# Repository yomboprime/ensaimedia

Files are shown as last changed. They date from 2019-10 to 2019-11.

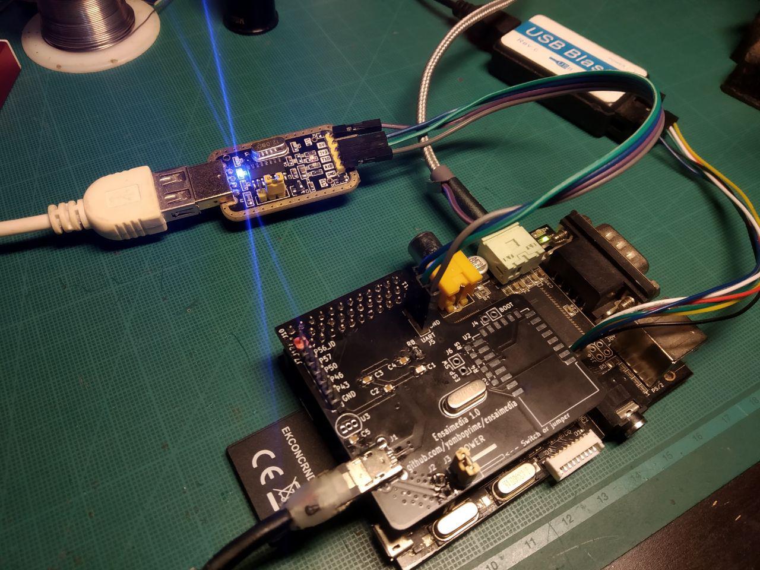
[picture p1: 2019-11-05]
screenshots/foto3.jpeg

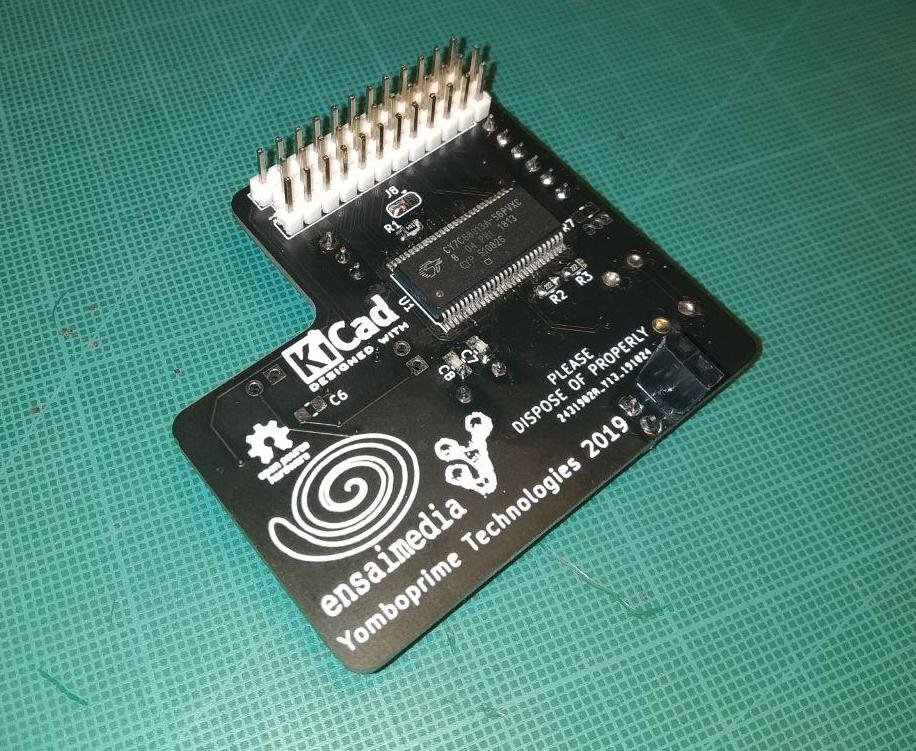
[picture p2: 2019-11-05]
screenshots/foto2.jpeg

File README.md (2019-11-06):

# Ensaimedia

Ensaimedia permite ver la salida de vídeo de un ZX-Uno o otra FPGA en un ordenador con USB host. Adicionalmente permite redireccionar el teclado, ratón y gamepads del host al ZX-Uno vía puerto serie. La salida de sonido del ZX-Uno también es capturada por el host si dispone de entrada de MIC o de línea de audio. La visualización se realiza desde el navegador web, ya sea en el host, o en otro dispositivo remoto. Por último, permite capturar vídeo y audio a disco.

El desarrollo de este addon ha sido posible gracias a la información y software de Wolfgang Wieser sobre el chip Cypress FX2 [en este sitio web.](https://www.triplespark.net/elec/periph/USB-FX2)

# Índice

En este README:
- [Guía de usuario](https://github.com/yomboprime/ensaimedia#guia-de-usuario-de-ensaimedia)
- [Documentación del protocolo](https://github.com/yomboprime/ensaimedia#documentaci%C3%B3n-ensaimedia)

En este repositorio:
- [Binarios de los cores](https://github.com/yomboprime/ensaimedia/tree/master/cores/)
- [Esquemático y PCB (en formato Kicad)](https://github.com/yomboprime/ensaimedia/tree/master/ensaimediaBoard)
- [Esquemático en formato PDF](https://github.com/yomboprime/ensaimedia/tree/master/ensaimediaBoard/ensaimedia.pdf)
- [Código del servidor](https://github.com/yomboprime/ensaimedia/blob/master/server.js)
- [Código del cliente](https://github.com/yomboprime/ensaimedia/blob/master/client/src/client.js)

# Guia de usuario de Ensaimedia

## Requisitos en el ZX-Uno

Necesitas el addon de Ensaimedia para tu FPGA, así como instalar el core de Ensaimedia de tu máquina retro.

Actualmente sólo está disponible el core oficial de ZX-Uno para ZX Spectrum.

## Requisitos del software Ensaimedia del host:

El host debe ser un sistema Unix, debido a que se usa el programa [fx2pipe](https://www.triplespark.net/elec/periph/USB-FX2/software/fx2pipe.html) para la entrada de vídeo por USB. El cliente (o clientes) puede ser cualquier sistema con un navegador web moderno.

- Ejecuta lo siguiente para instalar los requisitos previos:

`sudo apt install git npm libusb-dev build-essential`

- Pon a tu usuario en el grupo dialout para poder acceder al puerto serie:

`sudo adduser <nombre_de_usuario> dialout`

(Necesitas salir de la sesión o reiniciar para aplicar la adición al grupo, pero puedes reiniciar al terminar la instalación)

## Instalación del software Ensaimedia

Ve al directorio que se desea contenga el directorio de Ensaimedia.

Ejecuta:

```
git clone https://github.com/yomboprime/ensaimedia.git
cd ensaimedia
npm install
```

Adicionalmente hay que instalar unas reglas UDEV. Para ello ejecuta lo siguiente desde el directorio de Ensaimedia:

`sudo cp ./udevrules/z70_usbfx2.rules /etc/udev/rules.d`

Despues reinicia.

## Configuración del software

Edita el fichero `EnsaimediaConfig.json` que está en la raíz de la aplicación:

Como mínimo querrás cambiar el puerto TCP en el que sirve Ensaimedia (opción `listenPort`)

La ruta del fichero del puerto serie se cambia en la opción `serialPortFilePath`.

Si vas a usar audio necesitas primero identificar el dispositivo de audio de tu tarjeta de sonido. Para ello ejecuta:

`arecord -L`

Y verás una lista de dispositivos de entrada de audio. Tendrás que ir probando hasta dar con el mejor; algunos pueden funcionar peor o tener lag.

Copia la primera línea de uno de ellos y pégala (entre comillas) en la opción "audioDevice" en el fichero de configuración.

Para las opciones de guardado a disco mira la sección "Captura a disco" de esta documentación.

## Ejecución de Ensaimedia

Para utilizar Ensaimedia sigue estos pasos:

- Enciende el host.
- Conecta la FPGA al host (ver sección correspondiente más abajo)
- Activa en la FPGA el core deseado de Ensaimedia
- Ejecuta el software de Ensaimedia en el host.

Para ejecutar Ensaimedia sirve una cualquiera de estas tres variantes (en el directorio de Ensaimedia):

- `./Ensaimedia.sh`
- `node server.js`
- `npm start`

Para terminar el programa en cualquier momento, pulsa Ctrl-c en la consola donde lo has abierto.

Al ejecutar verás algunos mensajes indicando los recursos que está abriendo el programa. Si todo va bien, al cabo de un segundo verás el mensaje "New graphic mode: XXXxYYY", que indica que se ha activado el vídeo con esa resolución.

Ahora abre desde un navegador la url: `http://<IP del host>:<puerto TCP configurado>/main.html`

Por ejemplo, si estás abriendo el navegador desde el propio host y el puerto que editaste en `EnsaimediaConfig.json` fue el 12345, abre la url:

`http://127.0.0.1:12345/main.html`

Al abrir la URL ya deberá verse la pantalla de vídeo de la retromáquina.

## Uso de Ensaimedia

El teclado, ratón y dos gamepads funcionan de forma transparente.

Para activar el sonido debes ir al menú, arriba a la derecha (las páginas HTML no permiten reproducción de sonido sin intervención del usuario)

En el menú verás algunas opciones visuales:

- `Pixelated screen`: Hace que los píxels se vean nítidos en vez de interpolados. Nota: De momento no funciona en Firefox.
- `Interlazed`: Mezcla dos fotogramas consecutivos para ver correctamente demos con entrelazado.
- `Resolution is múltiple`: Hace que la resolución de salida sea múltiplo de la nativa de la máquina. Si está desactivada entonces la pantalla se ajusta mejor al espacio disponible pero puede haber píxeles irregulares.
- `Show info on screen`: Muestra en la esquina superior izquierda información de frames por segundo, clientes conectados y audio.
- `Toggle full screen`: Cambia entre modo pantalla completa y ventana.
- `Audio enabled`: Habilita el sonido.
- `Input options`: Aqui puedes activar o desactivar el envío de eventos de teclado, ratón y gamepads.
- `Open/close Controls`: Minimiza o expande el menú.

## Captura a disco

Para activar la captura a disco, establece a `true` los valores `saveVideoToDiskEnabled` y/o `saveAudioToDiskEnabled` en el fichero de configuración `EnsaimediaConfig.json`.

La captura se realiza en el host, los clientes del navegador no pueden afectar a esta.

La captura comenzará tan pronto como haya señal de vídeo, y la sesión se guardará en una carpeta nueva bajo `Ensaimedia/savedSessions/` (con nombre dependiente de la fecha y hora) como dos ficheros: `video.bin` con el vídeo en raw, y `audio.wav` con el audio. Estos ficheros continuarán creciendo mientras esté funcionando el programa, a un ritmo aproximado de 500 MB por minuto (para el core de ZX Spectrum con vídeo y audio).

Tras finalizar la sesión de Ensaimedia hay que postprocesar los datos raw para generar un vídeo comprimido webm "píxel perfect" que se pueda reproducir. Este proceso puede tardar 10 veces lo que dura el vídeo. Para ello:

- Abre un terminal de consola en la carpeta de Ensaimedia
- Ejecuta la orden `node convertCapture.js <carpeta> ni FPS`, donde:
	- `<carpeta>` es el nombre de la subcarpeta bajo `savedSessions`, sin barras.
	- `ni` Significa "not interlazed". Pon `i` en su lugar si quieres que se mezclen fotogramas dos a dos para desentrelazar el vídeo (el vídeo de salida tendrá la mitad de FPS)
	- FPS son los FPS originales del vídeo, 50 para el core de  ZX Spectrum. Puede contener decimales. El valor es independiente de si seleccionas entrelazado o no.

Este proceso convierte el vídeo raw a imágenes `.png` que ocupan otro tanto, y después llama al programa `ffmpeg` para crear el vídeo webm. En todo momento se muestra el estado de la conversión.

Al terminar se habrá creado el fichero `video.webm` en la subcarpeta de la sesión. Puedes entonces borrar el resto de ficheros. Puedes volver a crear el vídeo en cualquier momento si los ficheros `video.bin` y `audio.wav` están presentes (el fichero de audio es opcional)

## Conexión del ZX-Uno al host

Hay tres conexiones por cable entre el host y la FPGA: Un cable microUSB para el vídeo, un puerto serie para periféricos y RTC, y el cable de audio analógico.

Muy importante (Sólo para ZX-Uno): No conectes el microUSB de alimentación normal del ZX-Uno mientras usas el addon de Ensaimedia. Tanto el ZX-Uno como el addon son alimentados por el cable microUSB de éste último.

### Cable MicroUSB

Este cable conecta el host a la FPGA mediante un cable microUSB con líneas de datos (hay cables que sólo sirven para cargar y no tienen los cables que transportan los datos, sólo los de alimentación)

Este cable alimenta al ZX-Uno y al addon.

Es importante que el puerto del host sea USB 2.0 o superior. No sirve USB 1.0 ó 1.1.

### Cable puerto serie

Si el host tiene puerto serie de 3.3V accesible, puedes conectarlo directamente con tres cables Dupont (los comunes de 2.54 mm de separación). Si no, necesitarás un dongle USB Serial **que tenga jumper para configurarse a 3.3V (5V no vale)** y ocupar un puerto USB más.

La conexión de los tres cables Dupont en cualquier caso es la siguiente (verás el conector en el addon indicado como "serial" y los pines "RX", "TX" y "GND":

```
RX de la FPGA <--- TX del dongle
TX de la FPGA ---> RX del dongle
GND de la FPGA --- GND del dongle
```

### Cable de audio

Es un simple cable de audio estéreo minijack macho-macho. Se conecta desde la salida de sonido de la FPGA a la entrada de mic o de línea en el host.

Puede que necesites usar alsamixer para ajustar el volumen de la entrada.

## Problemas conocidos

En el propio host y en red local (LAN) el sonido funciona bien. Sin embargo, debido a que se usa WebRTC, para usar el sonido en Ensaimedia desde dispositivos que no tienen una IP pública (o si el host no tiene IP pública) habría que usar un "TURN server". No se ha implementado aún esta posibilidad, al no existir servidores TURN de acceso público.

-------------------------------------

# Documentación Ensaimedia

Ensaimedia consiste en una interfaz de comunicación entre un ZX-Uno (o otra FPGA) y un host USB mediante USB 2.0, para transmisión de vídeo al host, además de una interfaz serie (UART) para transmitir información de periféricos desde el host al ZX-Uno. Adicionalmente el software del host permite entrada y salida de audio analógico, conectando LINE y EAR del ZX-Uno a MIC y LINE del host.

Esto permite:

- Usar la salida HDMI del host (o cualquier salida futura) como nativa del core de ZX-Uno.
- Usar periféricos USB en el host como entrada en el ZX-Uno: Teclado, ratón y gamepads.
- Virtualizar completamente el ZX-Uno y hacerlo disponible a clientes web, cada uno con sus periféricos y recepción de vídeo y audio.
- Capturar a disco la sesión de vídeo y audio.

Las salidas de vídeo nativas así como los periféricos nativos del ZX-Uno se pueden usar a la vez que Ensaimedia, o bien se pueden dejar desconectados.

# Interfaz física de Ensaimedia

## Interfaz de vídeo

La interfaz de vídeo en Ensaimedia 1.0 consiste en un bus síncrono en el que el ZX-Uno es el master, y un chip Cypress CY7C68013A-56PVXC (FX2LP) lee ese bus y envía los datos por USB 2.0.

El bus es de 16 bits de ancho. El máximo ancho de banda teórico del bus es 48 MHz * 2 = 96 Mbytes/s. Pero el máximo transferible por USB 2.0 es aproximadamente 42 Mbytes/s, usando el programa [fx2pipe](https://www.triplespark.net/elec/periph/USB-FX2/software/fx2pipe.html), qué solo permite transmitir en una dirección. Otros drivers/librerías permiten transferencia bidireccional pero con menos ancho de banda.

Las señales de control del bus son (out es en dirección al host, in es en dirección al ZX-Uno):

- SLCLK (out) Reloj del bus síncrono proporcionado por el core del ZX-Uno. Debe estar entre 5 y 48 MHz y ser estable.
- SLWR (out) Señal de escritura (de un word de 16 bits) al bus (El ZX-Uno escribe)
- SLRD (out) Señal de lectura desde el bus (El ZX-Uno lee) (*)
- AVAILABLE (in): Pin que indica que hay un word disponible para lectura para el ZX-Uno. (*)

(*) Esta capacidad es posible en el addon de ZX-Uno Ensaimedia 1.0, pero no es usada por el sistema Ensaimedia para la salida de vídeo. Otros cores/experimentos pueden hacer uso de ella. Para conseguir dirección de datos desde el host a la FPGA en ensaimedia 1.0 se debe cambiar el "solder jumper" J8 a GND (pin 1 de J8). Para uso de ensaimedia debe estar a 3V3 (pin 3 de J8) El pin del FX2 en concreto es ADDR1: Dirección específica del FX2LP (número de endpoint). Es decir, este bit debe valer 1 para dirección de transmisión del ZX-Uno al host, y 0 para la dirección contraria.

## Interfaz serie

La interfaz serie para periféricos entre el ZX-Uno y el host USB es una UART estándar a 3.3V y 115200 baudios, 8 bits de datos, 1 bit stop, sin paridad ni control de flujo. Se usan ambos pines RX y TX.

# Protocolo Ensaimedia

## Formato de video de Ensaimedia

El ZX-Uno transmite al host comandos completos que son palabras de 16 bits de ancho. Estos comandos especifican el formato de vídeo y transfieren los valores RGB de los píxels.

Los comandos X_RES, Y_RES, MODE, START_FRAME y PIXEL son obligatorios en cada frame.

### Comando: PIXEL

Especifica un pixel según el formato seleccionado (ver comando MODE)

Según el formato de pixel seleccionado, cada pixel pueden estar dividido en varios comandos (words) diferentes.

### Comando: START_FRAME

1000000000000000 : marca de inicio de frame. El host espera un frame completo (dos START_FRAME) antes de comenzar a procesar el vídeo y darlo como válido.

### Comando: X_RES

101XXXXXXXXXXXXX : ajustar resolucion horizontal a X + 1 (X es de 13 bits, resolución desde 1 pixel hasta 8K pixels). Aplica en el siguiente inicio de frame.

### Comando: Y_RES

110YYYYYYYYYYYYY : ajustar resolucion vertical a Y + 1 (X es de 13 bits, resolución desde 1 pixel hasta 8K pixels) Aplica en el siguiente inicio de frame.

### Comando: MODE

111xxxxxmmmmRRFF : Establecer modo de pixel, reflexión (flip) y posterior rotación.

- m:
	- 0000: modo Spectrum ZX-Uno R3G3B3.
		- Formato del comando de pixel (1 word): 16'b0000000RRRGGGBBB
	- 0001: modo R5G5B5.
		- Formato del comando de pixel (1 word): 16'b0RRRRRGGGGGBBBBB
	- 0010: modo R8G8B8.
		- Formato del comando de pixel (2 words): 16'b0000GGGGRRRRRRRR, 16'b0001GGGGBBBBBBBB.
		- El primer word contiene el nibble de mayor peso del canal G.
	- 0011: modo R8G8B8.
		- Formato del comando de pixel (3 words): 16'b00000000RRRRRRRR, 16'b00000001GGGGGGGG, 16'b00000010BBBBBBBB
	- Otros valores: No definido aún

- x: reservado para futuros usos según el valor de m.

- FF = Reflexión: 00 no reflexión, 01 reflexion horizontal, 10 vertical, 11 ambas.

- RR = Rotación: 00 normal, 01 = 90 grados sentido horario, 10 = 180 grados, 11 = 270 grados

Notas:

La rotación de la imagen se aplica después de la reflexión.

Este comando aplica en el siguiente inicio de frame.

Múltiples comandos MODE son posibles en un mismo frame, según futuros usos.

## Formato de transmisión de los periféricos de Ensaimedia

Ensaimedia puede aunar diferentes periféricos de entrada de varios usuarios online (además de los del host) en una sola interfaz serie.

Los periféricos que provee la interfaz de Ensaimedia son:

- Un teclado PS/2
- Un ratón PS/2 con tres botones (sin rueda)
- Dos joysticks digitales de cuatro direcciones y 8 botones cada uno

En el core de ZX Spectrum no están implementados, sencillamente por no haber: el tercer botón del ratón, ni el segundo joystick con sus botones. Y el primer joystick sólo tiene dos botones.

Una transmisión completa consiste en una trama desde el host al ZX-Uno, y otra trama de respuesta desde el ZX-Uno al host. Este ciclo se repite a disposición del host.

### Trama Host -> ZX-Uno:

La secuencia de bytes de la trama es:

- 0x34: Inicio de frame
- 1 byte de configuración
- 1 byte joyDir: udlrudlr JoyUp1, JoyDown1, JoyLeft1, JoyRight1, JoyUp2, JoyDown2, JoyLeft2, JoyRight2
- 1 byte joyBtn1: 8 botones del Joystick1
- 1 byte joyBtn2: 8 botones del Joystick2
- 1 byte numBytesKeyb:  Num. bytes de PS2 de teclado. Si no hay, a 0. Max 255
- 1 byte numBytesMouse:  Num. bytes de PS2 de ratón. Si no hay, a 0. Max 255
- bytes de teclado, si los hay
- bytes de ratón, si los hay
- bytes de fecha y hora. Si el Formato es 0: No hay bytes de fecha y hora. Formato 1: 16 bytes; Formato 2: 8 bytes. Formato 3: variable, terminado en el byte 0x00.

#### Byte de configuración

011000ff

- ff: Formato de fecha y hora (0 al 3) en esta trama. Otros formatos de hora diferentes al deseado por el ZX-Uno serán ignorados por éste.

Otros valores del byte son reservados.

#### Formatos de fecha y hora:

Ensaimedia implementa un módulo de tiempo real o RTC. El host envía el tiempo cada segundo, pudiéndose transmitir en varios formatos. En el core de Spectrum del ZX-Uno el módulo se traduce en la implementación de los puertos del addon RTC del DivMMC. Hay que tener en cuenta que este addon no implementa husos horarios, por lo que siempre se mostrará la hora UTC para compatibilizar la hora de los ficheros en sistemas de almacenamiento modernos. El puerto usado para el RTC en el core Spectrum es el 0xCXEF (X = don't care)

Los formatos de fecha y hora posibles son:

- Formato 0: No hay fecha y hora (valor por defecto al empezar la transmisión)

- Formato 1: Formato del chip RTC242X (addon DivMMC)

	16 bytes con los valores de los registros del chip.

	Nota: Los días de la semana del 0 al 6 empiezan en Domingo.

	Ver datasheet del chip para más información.

- Formato 2: Timestamp

	8 bytes con un entero de 64 bits sin signo (more significant byte first) con los milisegundos transcurridos desde 00:00:00 UTC del 1 de enero de 1970.

- Formato 3: Formato flexible de usuario.

	En este formato se transmite una cadena de bytes de longitud arbitraria y formato definido por el usuario, y terminada en el byte 0.

	Lo que se haga con esa cadena en el core de ZX-Uno depende del core concreto. El comportamiento por defecto es leer la cadena e ignorarla.

### Respuesta del ZX-Uno al host: byte de ack

101000ff

ff: Formato de hora deseado, 0 al 3 (para las próximas tramas)

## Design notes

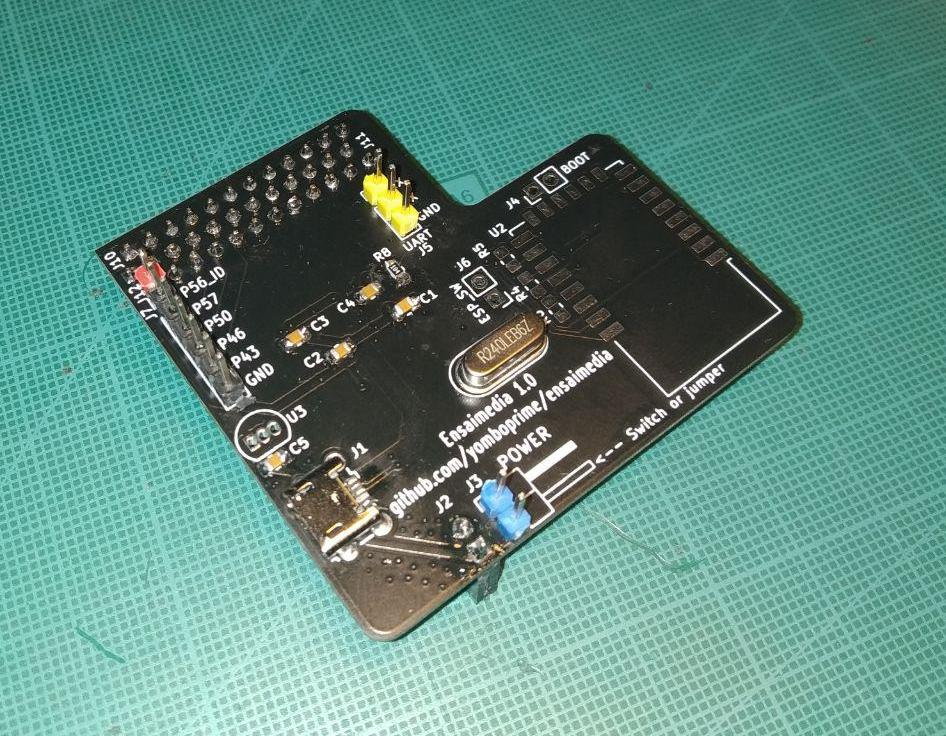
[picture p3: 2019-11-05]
screenshots/foto1.jpeg

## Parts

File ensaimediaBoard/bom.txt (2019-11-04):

BOM Ensaimedia 1.0

Componentes principales:

U1						CY7C68013A-56PVX
C1, C2, C3, C4, C5		0.1 uF 0805 decoupling caps
Y1						24 MHz crystal HC-49S. Important: must be Fundamental Mode (consult datasheet)
C7, C8					12 pF caps 0805
R1, R8					100 KOhm 0805
R2, R3					2.2 KOhm 0805
J1						MicroUSB Werth connector
J10, J11, J12			10p 2.54mm male pin headers
J2						2p 2.54mm female pin header
J3						2p 2.54mm male pin header OR Switch

EEPROM (opcional):

U3						DS2431 1-Wire EEPROM
R7						1 KOhm 0805

Componentes del WiFi (opcional):

U2						ESP-12E
R4, R5, R6				10 KOhm 0805
C6						0.1 uF 0805 decoupling cap
J4						2p 2.54mm male pin header OR Switch

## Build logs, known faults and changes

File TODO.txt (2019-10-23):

TESTS por hacer

------

IDEAS

------

BUGS

- tecla bloqdespl se cuelga?

------

TODO cliente

- Asignacion de player para los dos gamepads conectados

- (baja prioridad) teclado y joystick en pantalla. el teclado diferentes versiones con imagen svg

------

TODO programa host

- Captura: ajustar aspecto de cada frame al del tamaño del video (si son diferentes)

------

TODO Core

- mirar si hay q poner timeout en los perifericos. al cambiar de core se puede interrumpir la comunicacion

- implementar modo timex 512x192

- uart esp

- hacer version para 2M

------

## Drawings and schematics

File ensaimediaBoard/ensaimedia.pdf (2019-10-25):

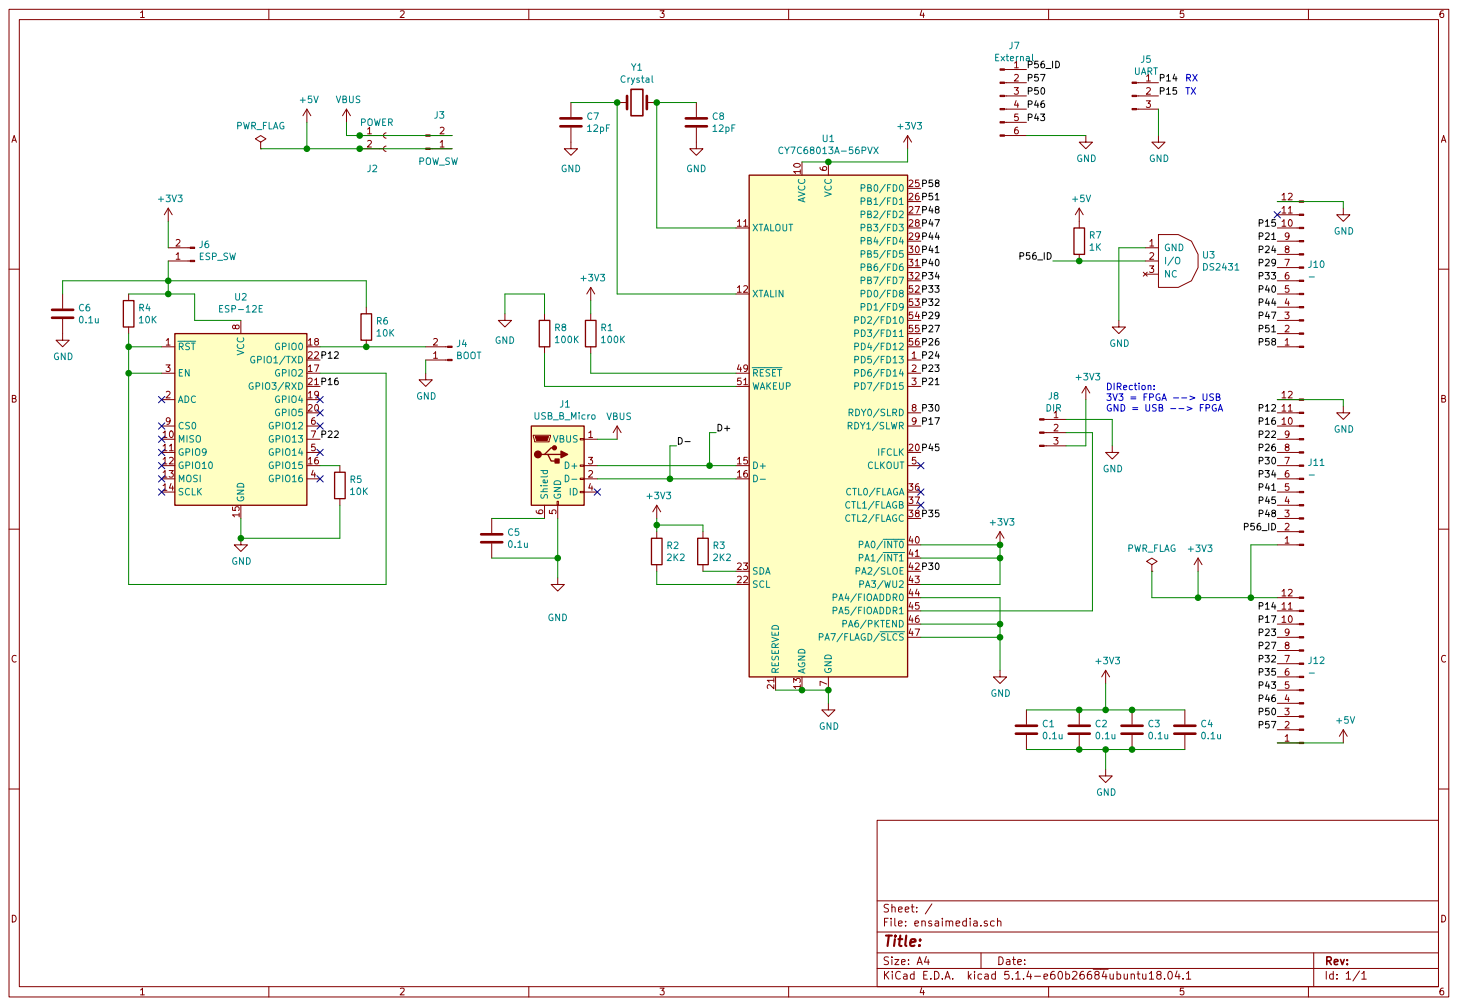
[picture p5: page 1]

TX DIRection: 3V3 = FPGA --> USB GND = USB --> FPGA

Id: 1/1 Title: File: ensaimedia.sch Sheet: /

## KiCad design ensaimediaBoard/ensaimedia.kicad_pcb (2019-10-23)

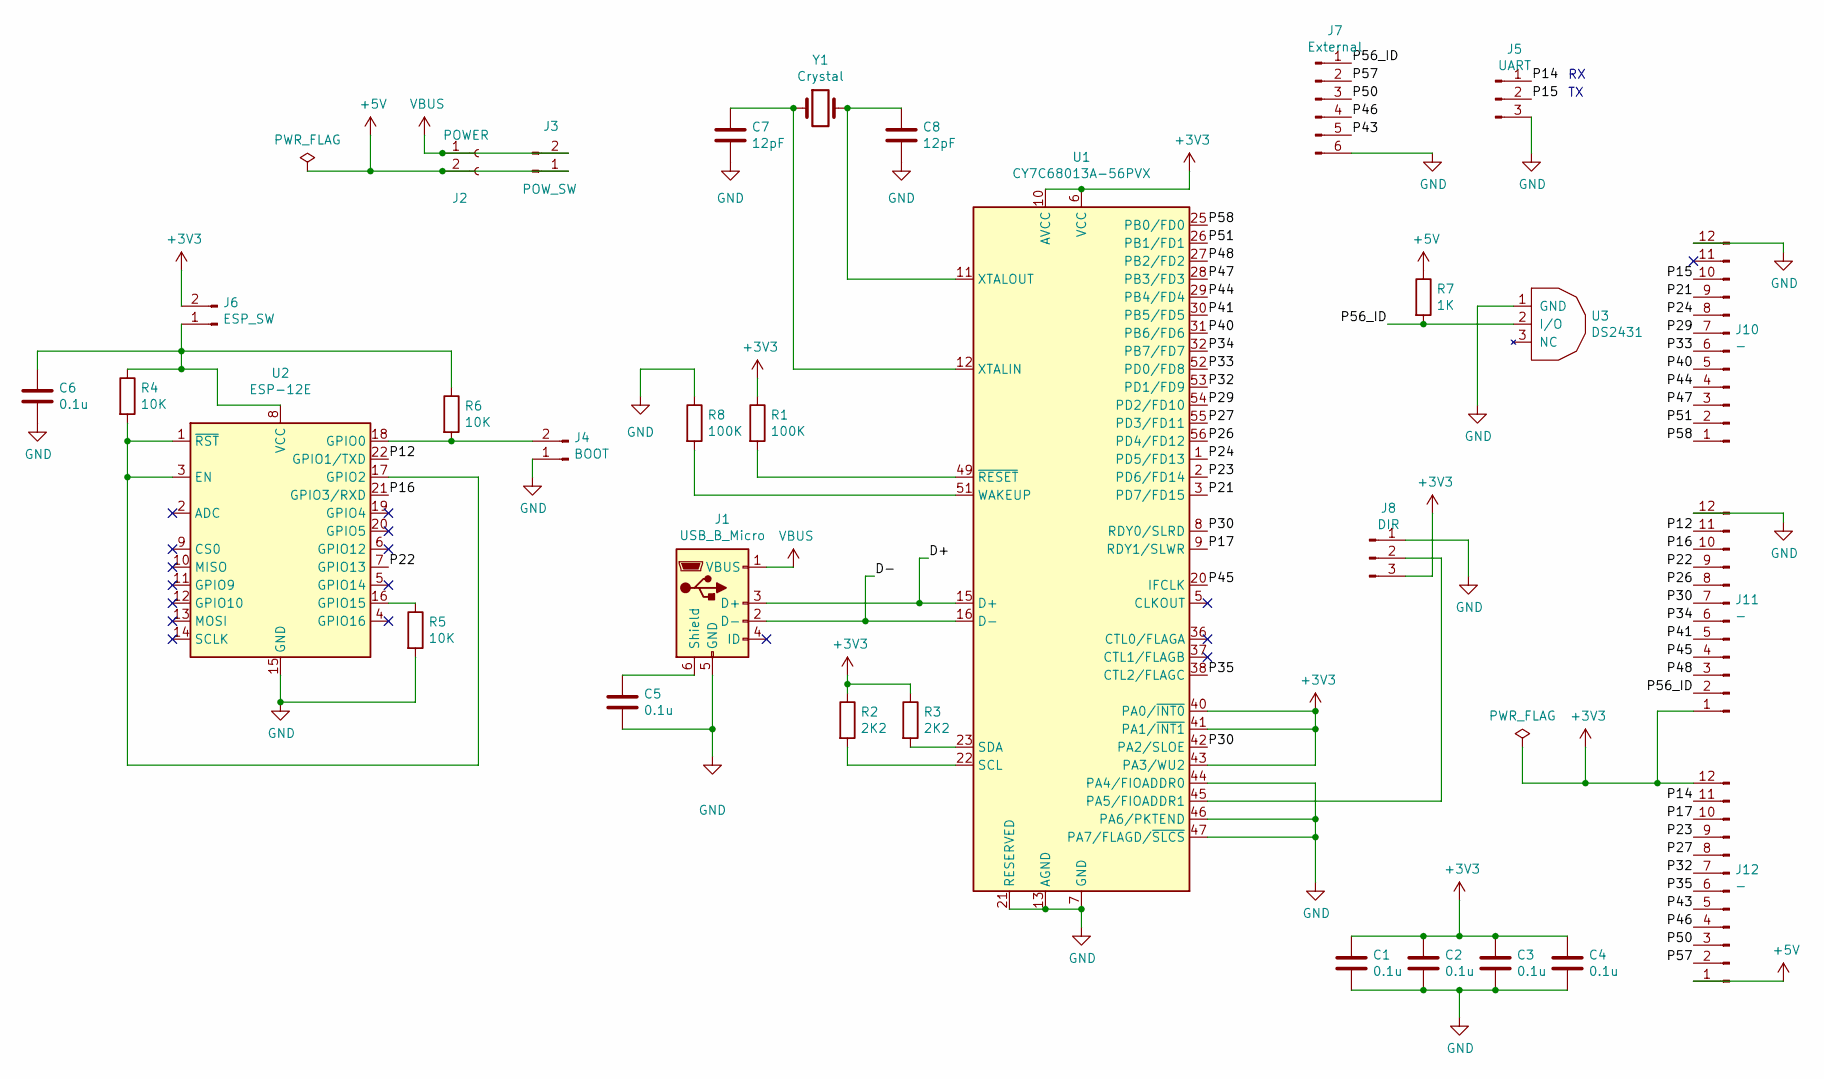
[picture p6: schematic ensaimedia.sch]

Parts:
C1, C2, C3, C4, C5, C6: 0.1u; C_0805_2012Metric_Pad1.15x1.40mm_HandSolder
C7, C8: 12pF; C_0805_2012Metric_Pad1.15x1.40mm_HandSolder
J1: USB_B_Micro; USB_Micro-B_Wuerth_629105150521_CircularHoles
J2: POWER; PinHeader_1x02_P2.54mm_Vertical
J3: POW_SW; PinHeader_1x02_P2.54mm_Horizontal
J4: BOOT; PinHeader_1x02_P2.54mm_Vertical
J5: UART; PinHeader_1x03_P2.54mm_Vertical
J6: ESP_SW; PinHeader_1x02_P2.54mm_Vertical
J7: External; PinHeader_1x06_P2.54mm_Vertical
J8: DIR; SolderJumper-3_P1.3mm_Open_RoundedPad1.0x1.5mm
J10, J11, J12: -; PinHeader_1x12_P2.54mm_Vertical
R1, R8: 100K; R_0805_2012Metric_Pad1.15x1.40mm_HandSolder
R2, R3: 2K2; R_0805_2012Metric_Pad1.15x1.40mm_HandSolder
R4, R5, R6: 10K; R_0805_2012Metric_Pad1.15x1.40mm_HandSolder
R7: 1K; R_0805_2012Metric_Pad1.15x1.40mm_HandSolder
U1: CY7C68013A-56PVX; SSOP-56_7.5x18.5mm_P0.635mm
U2: ESP-12E
U3: DS2431; TO-92_Inline
Y1: Crystal; Crystal_HC49-U_Vertical

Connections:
+3V3: C1.1, C2.1, C3.1, C4.1, J6.2, J8.3, J11.1, J12.12, R1.1, R2.1, R3.1, U1.6 (VCC), U1.10 (AVCC), U1.14 (AVCC), U1.18 (VCC), U1.24 (VCC), U1.34 (VCC), U1.39 (VCC), U1.40 (PA0/~INT0), U1.41 (PA1/~INT1), U1.43 (PA3/WU2), U1.50 (VCC)
+5V: J2.2, J3.1, J12.1, R7.1
/D+: J1.3 (D+), U1.15 (D+)
/D-: J1.2 (D-), U1.16 (D-)
/P12: J11.11, U2.22 (GPIO1/TXD)
/P14: J5.1, J12.11
/P15: J5.2, J10.10
/P16: J11.10, U2.21 (GPIO3/RXD)
/P17: J12.10, U1.9 (RDY1/SLWR)
/P21: J10.9, U1.3 (PD7/FD15)
/P22: J11.9, U2.7 (GPIO13)
/P23: J12.9, U1.2 (PD6/FD14)
/P24: J10.8, U1.1 (PD5/FD13)
/P26: J11.8, U1.56 (PD4/FD12)
/P27: J12.8, U1.55 (PD3/FD11)
/P29: J10.7, U1.54 (PD2/FD10)
/P30: J11.7, U1.8 (RDY0/SLRD), U1.42 (PA2/SLOE)
/P32: J12.7, U1.53 (PD1/FD9)
/P33: J10.6, U1.52 (PD0/FD8)
/P34: J11.6, U1.32 (PB7/FD7)
/P35: J12.6, U1.38 (CTL2/FLAGC)
/P40: J10.5, U1.31 (PB6/FD6)
/P41: J11.5, U1.30 (PB5/FD5)
/P43: J7.5, J12.5
/P44: J10.4, U1.29 (PB4/FD4)
/P45: J11.4, U1.20 (IFCLK)
/P46: J7.4, J12.4
/P47: J10.3, U1.28 (PB3/FD3)
/P48: J11.3, U1.27 (PB2/FD2)
/P50: J7.3, J12.3
/P51: J10.2, U1.26 (PB1/FD1)
/P56_ID: J7.1, J11.2, R7.2, U3.2 (I/O)
/P57: J7.2, J12.2
/P58: J10.1, U1.25 (PB0/FD0)
GND: C1.2, C2.2, C3.2, C4.2, C5.2, C6.2, C7.2, C8.2, J1.5 (GND), J4.1, J5.3, J7.6, J8.1, J10.12, J11.12, R5.2, R8.1, U1.4 (GND), U1.7 (GND), U1.13 (AGND), U1.17 (AGND), U1.19 (GND), U1.21 (RESERVED), U1.33 (GND), U1.35 (GND), U1.44 (PA4/FIOADDR0), U1.46 (PA6/PKTEND), U1.47 (PA7/FLAGD/~SLCS), U1.48 (GND), U2.15 (GND), U3.1 (GND)
unnamed: C5.1, J1.6 (Shield)
unnamed: C6.1, J6.1, R4.1, R6.1, U2.8 (VCC)
unnamed: C7.1, U1.12 (XTALIN), Y1.1
unnamed: C8.1, U1.11 (XTALOUT), Y1.2
unnamed: J4.2, R6.2, U2.18 (GPIO0)
unnamed: J8.2, U1.45 (PA5/FIOADDR1)
unnamed: R1.2, U1.49 (~RESET)
unnamed: R2.2, U1.22 (SCL)
unnamed: R3.2, U1.23 (SDA)
unnamed: R4.2, U2.1 (~RST), U2.3 (EN), U2.17 (GPIO2)
unnamed: R5.1, U2.16 (GPIO15)
unnamed: R8.2, U1.51 (WAKEUP)
VBUS: J1.1 (VBUS), J2.1, J3.2

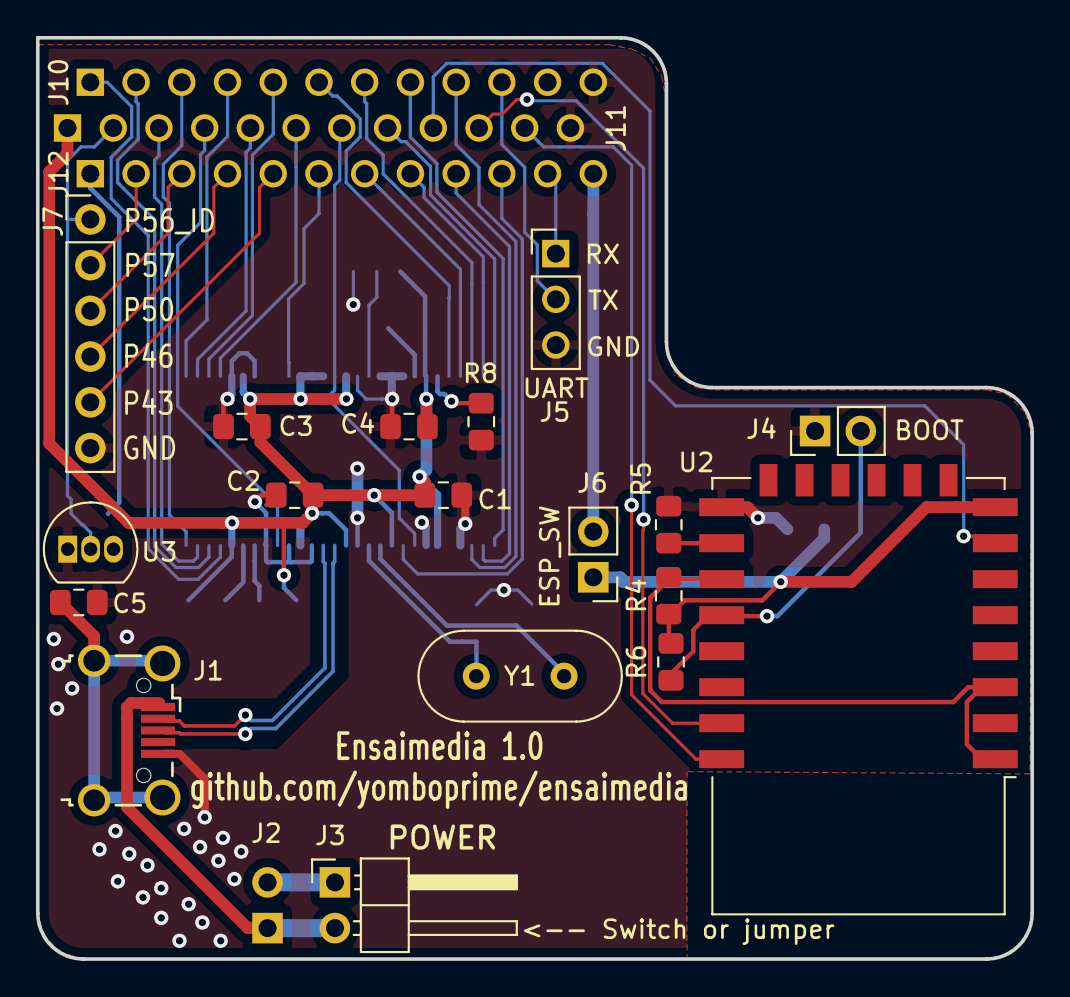
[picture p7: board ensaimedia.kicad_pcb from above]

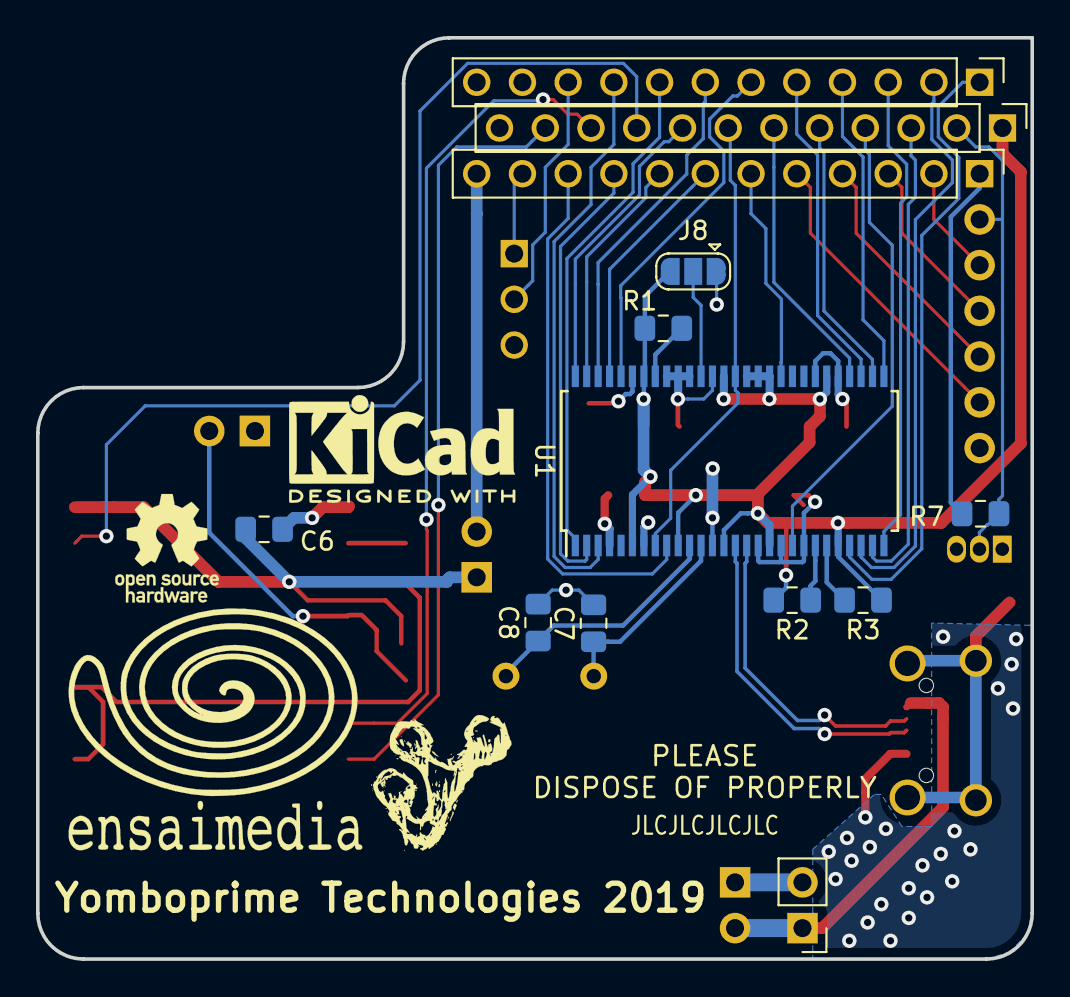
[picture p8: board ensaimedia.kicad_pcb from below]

Board: 2 copper layers, 55.2 x 51.2 mm, 31 parts (13 on the bottom side), 48 nets.

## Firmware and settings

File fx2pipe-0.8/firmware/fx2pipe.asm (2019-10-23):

;--------------------------------------------------------
; File Created by SDCC : free open source ANSI-C Compiler
; Version 2.8.0 #5117 (May 29 2008) (UNIX)
; This file was generated Wed Apr 29 00:40:33 2009
;--------------------------------------------------------
	.module fx2pipe
	.optsdcc -mmcs51 --model-small
	
;--------------------------------------------------------
; Public variables in this module
;--------------------------------------------------------
	.globl _main
	.globl _EIP
	.globl _B
	.globl _EIE
	.globl _ACC
	.globl _EICON
	.globl _PSW
	.globl _TH2
	.globl _TL2
	.globl _RCAP2H
	.globl _RCAP2L
	.globl _T2CON
	.globl _SBUF1
	.globl _SCON1
	.globl _GPIFSGLDATLNOX
	.globl _GPIFSGLDATLX
	.globl _GPIFSGLDATH
	.globl _GPIFTRIG
	.globl _EP01STAT
	.globl _IP
	.globl _OEE
	.globl _OED
	.globl _OEC
	.globl _OEB
	.globl _OEA
	.globl _IOE
	.globl _IOD
	.globl _AUTOPTRSETUP
	.globl _EP68FIFOFLGS
	.globl _EP24FIFOFLGS
	.globl _EP2468STAT
	.globl _IE
	.globl _INT4CLR
	.globl _INT2CLR
	.globl _IOC
	.globl _AUTODAT2
	.globl _AUTOPTRL2
	.globl _AUTOPTRH2
	.globl _AUTODAT1
	.globl _APTR1L
	.globl _APTR1H
	.globl _SBU
	.globl _SCO
	.globl _MPA
	.globl _EXIF
	.globl _IOB
	.globl _SPC_
	.globl _CKCO
	.globl _TH1
	.globl _TH0
	.globl _TL1
	.globl _TL0
	.globl _TMOD
	.globl _TCON
	.globl _PCON
	.globl _DPS
	.globl _DPH1
	.globl _DPL1
	.globl _DPH
	.globl _DPL
	.globl _SP
	.globl _IOA
	.globl _EP8FIFOBUF
	.globl _EP6FIFOBUF
	.globl _EP4FIFOBUF
	.globl _EP2FIFOBUF
	.globl _EP1INBUF
	.globl _EP1OUTBUF
	.globl _EP0BUF
	.globl _CT4
	.globl _CT3
	.globl _CT2
	.globl _CT1
	.globl _USBTEST
	.globl _TESTCFG
	.globl _DBUG
	.globl _UDMACRCQUAL
	.globl _UDMACRCL
	.globl _UDMACRCH
	.globl _GPIFHOLDAMOUNT
	.globl _FLOWSTBHPERIOD
	.globl _FLOWSTBEDGE
	.globl _FLOWSTB
	.globl _FLOWHOLDOFF
	.globl _FLOWEQ1CTL
	.globl _FLOWEQ0CTL
	.globl _FLOWLOGIC
	.globl _FLOWSTATE
	.globl _GPIFABORT
	.globl _GPIFREADYSTAT
	.globl _GPIFREADYCFG
	.globl _XGPIFSGLDATLNOX
	.globl _XGPIFSGLDATLX
	.globl _XGPIFSGLDATH
	.globl _EP8GPIFTRIG
	.globl _EP8GPIFPFSTOP
	.globl _EP8GPIFFLGSEL
	.globl _EP6GPIFTRIG
	.globl _EP6GPIFPFSTOP
	.globl _EP6GPIFFLGSEL
	.globl _EP4GPIFTRIG
	.globl _EP4GPIFPFSTOP
	.globl _EP4GPIFFLGSEL
	.globl _EP2GPIFTRIG
	.globl _EP2GPIFPFSTOP
	.globl _EP2GPIFFLGSEL
	.globl _GPIFTCB0
	.globl _GPIFTCB1
	.globl _GPIFTCB2
	.globl _GPIFTCB3
	.globl _GPIFADRL
	.globl _GPIFADRH
	.globl _GPIFCTLCFG
	.globl _GPIFIDLECTL
	.globl _GPIFIDLECS
	.globl _GPIFWFSELECT
	.globl _SETUPDAT
	.globl _SUDPTRCTL
	.globl _SUDPTRL
	.globl _SUDPTRH
	.globl _EP8FIFOBCL
	.globl _EP8FIFOBCH
	.globl _EP6FIFOBCL
	.globl _EP6FIFOBCH
	.globl _EP4FIFOBCL
	.globl _EP4FIFOBCH
	.globl _EP2FIFOBCL
	.globl _EP2FIFOBCH
	.globl _EP8FIFOFLGS
	.globl _EP6FIFOFLGS
	.globl _EP4FIFOFLGS
	.globl _EP2FIFOFLGS
	.globl _EP8CS
	.globl _EP6CS
	.globl _EP4CS
	.globl _EP2CS
	.globl _EP1INCS
	.globl _EP1OUTCS
	.globl _EP0CS
	.globl _EP8BCL
	.globl _EP8BCH
	.globl _EP6BCL
	.globl _EP6BCH
	.globl _EP4BCL
	.globl _EP4BCH
	.globl _EP2BCL
	.globl _EP2BCH
	.globl _EP1INBC
	.globl _EP1OUTBC
	.globl _EP0BCL
	.globl _EP0BCH
	.globl _FNADDR
	.globl _MICROFRAME
	.globl _USBFRAMEL
	.globl _USBFRAMEH
	.globl _TOGCTL
	.globl _WAKEUPCS
	.globl _SUSPEND
	.globl _USBCS
	.globl _XAUTODAT2
	.globl _XAUTODAT1
	.globl _I2CTL
	.globl _I2DAT
	.globl _I2CS
	.globl _PORTECFG
	.globl _PORTCCFG
	.globl _PORTACFG
	.globl _INTSETUP
	.globl _INT4IVEC
	.globl _INT2IVEC
	.globl _CLRERRCNT
	.globl _ERRCNTLIM
	.globl _USBERRIRQ
	.globl _USBERRIE
	.globl _GPIFIRQ
	.globl _GPIFIE
	.globl _EPIRQ
	.globl _EPIE
	.globl _USBIRQ
	.globl _USBIE
	.globl _NAKIRQ
	.globl _NAKIE
	.globl _IBNIRQ
	.globl _IBNIE
	.globl _EP8FIFOIRQ
	.globl _EP8FIFOIE
	.globl _EP6FIFOIRQ
	.globl _EP6FIFOIE
	.globl _EP4FIFOIRQ
	.globl _EP4FIFOIE
	.globl _EP2FIFOIRQ
	.globl _EP2FIFOIE
	.globl _OUTPKTEND
	.globl _INPKTEND
	.globl _EP8ISOINPKTS
	.globl _EP6ISOINPKTS
	.globl _EP4ISOINPKTS
	.globl _EP2ISOINPKTS
	.globl _EP8FIFOPFL
	.globl _EP8FIFOPFH
	.globl _EP6FIFOPFL
	.globl _EP6FIFOPFH
	.globl _EP4FIFOPFL
	.globl _EP4FIFOPFH
	.globl _EP2FIFOPFL
	.globl _EP2FIFOPFH
	.globl _EP8AUTOINLENL
	.globl _EP8AUTOINLENH
	.globl _EP6AUTOINLENL
	.globl _EP6AUTOINLENH
	.globl _EP4AUTOINLENL
	.globl _EP4AUTOINLENH
	.globl _EP2AUTOINLENL
	.globl _EP2AUTOINLENH
	.globl _EP8FIFOCFG
	.globl _EP6FIFOCFG
	.globl _EP4FIFOCFG
	.globl _EP2FIFOCFG
	.globl _EP8CFG
	.globl _EP6CFG
	.globl _EP4CFG
	.globl _EP2CFG
	.globl _EP1INCFG
	.globl _EP1OUTCFG
	.globl _REVCTL
	.globl _REVID
	.globl _FIFOPINPOLAR
	.globl _UART230
	.globl _BPADDRL
	.globl _BPADDRH
	.globl _BREAKPT
	.globl _FIFORESET
	.globl _PINFLAGSCD
	.globl _PINFLAGSAB
	.globl _IFCONFIG
	.globl _CPUCS
	.globl _RES_WAVEDATA_END
	.globl _GPIF_WAVE_DATA
;--------------------------------------------------------
; special function registers
;--------------------------------------------------------
	.area RSEG    (DATA)
_IOA	=	0x0080
_SP	=	0x0081
_DPL	=	0x0082
_DPH	=	0x0083
_DPL1	=	0x0084
_DPH1	=	0x0085
_DPS	=	0x0086
_PCON	=	0x0087
_TCON	=	0x0088
_TMOD	=	0x0089
_TL0	=	0x008a
_TL1	=	0x008b
_TH0	=	0x008c
_TH1	=	0x008d
_CKCO	=	0x008e
_SPC_	=	0x008f
_IOB	=	0x0090
_EXIF	=	0x0091
_MPA	=	0x0092
_SCO	=	0x0098
_SBU	=	0x0099
_APTR1H	=	0x009a
_APTR1L	=	0x009b
_AUTODAT1	=	0x009c
_AUTOPTRH2	=	0x009d
_AUTOPTRL2	=	0x009e
_AUTODAT2	=	0x009f
_IOC	=	0x00a0
_INT2CLR	=	0x00a1
_INT4CLR	=	0x00a2
_IE	=	0x00a8
_EP2468STAT	=	0x00aa
_EP24FIFOFLGS	=	0x00ab
_EP68FIFOFLGS	=	0x00ac
_AUTOPTRSETUP	=	0x00af
_IOD	=	0x00b0
_IOE	=	0x00b1
_OEA	=	0x00b2
_OEB	=	0x00b3
_OEC	=	0x00b4
_OED	=	0x00b5
_OEE	=	0x00b6
_IP	=	0x00b8
_EP01STAT	=	0x00ba
_GPIFTRIG	=	0x00bb
_GPIFSGLDATH	=	0x00bd
_GPIFSGLDATLX	=	0x00be
_GPIFSGLDATLNOX	=	0x00bf
_SCON1	=	0x00c0
_SBUF1	=	0x00c1
_T2CON	=	0x00c8
_RCAP2L	=	0x00ca
_RCAP2H	=	0x00cb
_TL2	=	0x00cc
_TH2	=	0x00cd
_PSW	=	0x00d0
_EICON	=	0x00d8
_ACC	=	0x00e0
_EIE	=	0x00e8
_B	=	0x00f0
_EIP	=	0x00f8
;--------------------------------------------------------
; special function bits
;--------------------------------------------------------
	.area RSEG    (DATA)
;--------------------------------------------------------
; overlayable register banks
;--------------------------------------------------------
	.area REG_BANK_0	(REL,OVR,DATA)
	.ds 8
;--------------------------------------------------------
; internal ram data
;--------------------------------------------------------
	.area DSEG    (DATA)
;--------------------------------------------------------
; overlayable items in internal ram 
;--------------------------------------------------------
	.area	OSEG    (OVR,DATA)
;--------------------------------------------------------
; Stack segment in internal ram 
;--------------------------------------------------------
	.area	SSEG	(DATA)
__start__stack:
	.ds	1

;--------------------------------------------------------
; indirectly addressable internal ram data
;--------------------------------------------------------
	.area ISEG    (DATA)
;--------------------------------------------------------
; absolute internal ram data
;--------------------------------------------------------
	.area IABS    (ABS,DATA)
	.area IABS    (ABS,DATA)
;--------------------------------------------------------
; bit data
;--------------------------------------------------------
	.area BSEG    (BIT)
;--------------------------------------------------------
; paged external ram data
;--------------------------------------------------------
	.area PSEG    (PAG,XDATA)
;--------------------------------------------------------
; external ram data
;--------------------------------------------------------
	.area XSEG    (XDATA)
_GPIF_WAVE_DATA	=	0xe400
_RES_WAVEDATA_END	=	0xe480
_CPUCS	=	0xe600
_IFCONFIG	=	0xe601
_PINFLAGSAB	=	0xe602
_PINFLAGSCD	=	0xe603
_FIFORESET	=	0xe604
_BREAKPT	=	0xe605
_BPADDRH	=	0xe606
_BPADDRL	=	0xe607
_UART230	=	0xe608
_FIFOPINPOLAR	=	0xe609
_REVID	=	0xe60a
_REVCTL	=	0xe60b
_EP1OUTCFG	=	0xe610
_EP1INCFG	=	0xe611
_EP2CFG	=	0xe612
_EP4CFG	=	0xe613
_EP6CFG	=	0xe614
_EP8CFG	=	0xe615
_EP2FIFOCFG	=	0xe618
_EP4FIFOCFG	=	0xe619
_EP6FIFOCFG	=	0xe61a
_EP8FIFOCFG	=	0xe61b
_EP2AUTOINLENH	=	0xe620
_EP2AUTOINLENL	=	0xe621
_EP4AUTOINLENH	=	0xe622
_EP4AUTOINLENL	=	0xe623
_EP6AUTOINLENH	=	0xe624
_EP6AUTOINLENL	=	0xe625
_EP8AUTOINLENH	=	0xe626
_EP8AUTOINLENL	=	0xe627
_EP2FIFOPFH	=	0xe630
_EP2FIFOPFL	=	0xe631
_EP4FIFOPFH	=	0xe632
_EP4FIFOPFL	=	0xe633
_EP6FIFOPFH	=	0xe634
_EP6FIFOPFL	=	0xe635
_EP8FIFOPFH	=	0xe636
_EP8FIFOPFL	=	0xe637
_EP2ISOINPKTS	=	0xe640
_EP4ISOINPKTS	=	0xe641
_EP6ISOINPKTS	=	0xe642
_EP8ISOINPKTS	=	0xe643
_INPKTEND	=	0xe648
_OUTPKTEND	=	0xe649
_EP2FIFOIE	=	0xe650
_EP2FIFOIRQ	=	0xe651
_EP4FIFOIE	=	0xe652
_EP4FIFOIRQ	=	0xe653
_EP6FIFOIE	=	0xe654
_EP6FIFOIRQ	=	0xe655
_EP8FIFOIE	=	0xe656
_EP8FIFOIRQ	=	0xe657
_IBNIE	=	0xe658
_IBNIRQ	=	0xe659
_NAKIE	=	0xe65a
_NAKIRQ	=	0xe65b
_USBIE	=	0xe65c
_USBIRQ	=	0xe65d
_EPIE	=	0xe65e
_EPIRQ	=	0xe65f
_GPIFIE	=	0xe660
_GPIFIRQ	=	0xe661
_USBERRIE	=	0xe662
_USBERRIRQ	=	0xe663
_ERRCNTLIM	=	0xe664
_CLRERRCNT	=	0xe665
_INT2IVEC	=	0xe666
_INT4IVEC	=	0xe667
_INTSETUP	=	0xe668
_PORTACFG	=	0xe670
_PORTCCFG	=	0xe671
_PORTECFG	=	0xe672
_I2CS	=	0xe678
_I2DAT	=	0xe679
_I2CTL	=	0xe67a
_XAUTODAT1	=	0xe67b
_XAUTODAT2	=	0xe67c
_USBCS	=	0xe680
_SUSPEND	=	0xe681
_WAKEUPCS	=	0xe682
_TOGCTL	=	0xe683
_USBFRAMEH	=	0xe684
_USBFRAMEL	=	0xe685
_MICROFRAME	=	0xe686
_FNADDR	=	0xe687
_EP0BCH	=	0xe68a
_EP0BCL	=	0xe68b
_EP1OUTBC	=	0xe68d
_EP1INBC	=	0xe68f
_EP2BCH	=	0xe690
_EP2BCL	=	0xe691
_EP4BCH	=	0xe694
_EP4BCL	=	0xe695
_EP6BCH	=	0xe698
_EP6BCL	=	0xe699
_EP8BCH	=	0xe69c
_EP8BCL	=	0xe69d
_EP0CS	=	0xe6a0
_EP1OUTCS	=	0xe6a1
_EP1INCS	=	0xe6a2
_EP2CS	=	0xe6a3
_EP4CS	=	0xe6a4
_EP6CS	=	0xe6a5
_EP8CS	=	0xe6a6
_EP2FIFOFLGS	=	0xe6a7
_EP4FIFOFLGS	=	0xe6a8
_EP6FIFOFLGS	=	0xe6a9
_EP8FIFOFLGS	=	0xe6aa
_EP2FIFOBCH	=	0xe6ab
_EP2FIFOBCL	=	0xe6ac
_EP4FIFOBCH	=	0xe6ad
_EP4FIFOBCL	=	0xe6ae
_EP6FIFOBCH	=	0xe6af
_EP6FIFOBCL	=	0xe6b0
_EP8FIFOBCH	=	0xe6b1
_EP8FIFOBCL	=	0xe6b2
_SUDPTRH	=	0xe6b3
_SUDPTRL	=	0xe6b4
_SUDPTRCTL	=	0xe6b5
_SETUPDAT	=	0xe6b8
_GPIFWFSELECT	=	0xe6c0
_GPIFIDLECS	=	0xe6c1
_GPIFIDLECTL	=	0xe6c2
_GPIFCTLCFG	=	0xe6c3
_GPIFADRH	=	0xe6c4
_GPIFADRL	=	0xe6c5
_GPIFTCB3	=	0xe6ce
_GPIFTCB2	=	0xe6cf
_GPIFTCB1	=	0xe6d0
_GPIFTCB0	=	0xe6d1
_EP2GPIFFLGSEL	=	0xe6d2
_EP2GPIFPFSTOP	=	0xe6d3
_EP2GPIFTRIG	=	0xe6d4
_EP4GPIFFLGSEL	=	0xe6da
_EP4GPIFPFSTOP	=	0xe6db
_EP4GPIFTRIG	=	0xe6dc
_EP6GPIFFLGSEL	=	0xe6e2
_EP6GPIFPFSTOP	=	0xe6e3
_EP6GPIFTRIG	=	0xe6e4
_EP8GPIFFLGSEL	=	0xe6ea
_EP8GPIFPFSTOP	=	0xe6eb
_EP8GPIFTRIG	=	0xe6ec
_XGPIFSGLDATH	=	0xe6f0
_XGPIFSGLDATLX	=	0xe6f1
_XGPIFSGLDATLNOX	=	0xe6f2
_GPIFREADYCFG	=	0xe6f3
_GPIFREADYSTAT	=	0xe6f4
_GPIFABORT	=	0xe6f5
_FLOWSTATE	=	0xe6c6
_FLOWLOGIC	=	0xe6c7
_FLOWEQ0CTL	=	0xe6c8
_FLOWEQ1CTL	=	0xe6c9
_FLOWHOLDOFF	=	0xe6ca
_FLOWSTB	=	0xe6cb
_FLOWSTBEDGE	=	0xe6cc
_FLOWSTBHPERIOD	=	0xe6cd
_GPIFHOLDAMOUNT	=	0xe60c
_UDMACRCH	=	0xe67d
_UDMACRCL	=	0xe67e
_UDMACRCQUAL	=	0xe67f
_DBUG	=	0xe6f8
_TESTCFG	=	0xe6f9
_USBTEST	=	0xe6fa
_CT1	=	0xe6fb
_CT2	=	0xe6fc
_CT3	=	0xe6fd
_CT4	=	0xe6fe
_EP0BUF	=	0xe740
_EP1OUTBUF	=	0xe780
_EP1INBUF	=	0xe7c0
_EP2FIFOBUF	=	0xf000
_EP4FIFOBUF	=	0xf400
_EP6FIFOBUF	=	0xf800
_EP8FIFOBUF	=	0xfc00
;--------------------------------------------------------
; absolute external ram data
;--------------------------------------------------------
	.area XABS    (ABS,XDATA)
;--------------------------------------------------------
; external initialized ram data
;--------------------------------------------------------
	.area XISEG   (XDATA)
	.area HOME    (CODE)
	.area GSINIT0 (CODE)
	.area GSINIT1 (CODE)
	.area GSINIT2 (CODE)
	.area GSINIT3 (CODE)
	.area GSINIT4 (CODE)
	.area GSINIT5 (CODE)
	.area GSINIT  (CODE)
	.area GSFINAL (CODE)
	.area CSEG    (CODE)
;--------------------------------------------------------
; interrupt vector 
;--------------------------------------------------------
	.area HOME    (CODE)
__interrupt_vect:
	ljmp	__sdcc_gsinit_startup
;--------------------------------------------------------
; global & static initialisations
;--------------------------------------------------------
	.area HOME    (CODE)
	.area GSINIT  (CODE)
	.area GSFINAL (CODE)
	.area GSINIT  (CODE)
	.globl __sdcc_gsinit_startup
	.globl __sdcc_program_startup
	.globl __start__stack
	.globl __mcs51_genXINIT
	.globl __mcs51_genXRAMCLEAR
	.globl __mcs51_genRAMCLEAR
	.area GSFINAL (CODE)
	ljmp	__sdcc_program_startup
;--------------------------------------------------------
; Home
;--------------------------------------------------------
	.area HOME    (CODE)
	.area HOME    (CODE)
__sdcc_program_startup:
	lcall	_main
;	return from main will lock up
	sjmp .
;--------------------------------------------------------
; code
;--------------------------------------------------------
	.area CSEG    (CODE)
;------------------------------------------------------------
;Allocation info for local variables in function 'Initialize'
;------------------------------------------------------------
;cfg_data                  Allocated to registers 
;cfg_data_ok               Allocated to registers r5 
;------------------------------------------------------------
;	fx2pipe.c:56: static void Initialize(void)
;	-----------------------------------------
;	 function Initialize
;	-----------------------------------------
_Initialize:
	ar2 = 0x02
	ar3 = 0x03
	ar4 = 0x04
	ar5 = 0x05
	ar6 = 0x06
	ar7 = 0x07
	ar0 = 0x00
	ar1 = 0x01
;	fx2pipe.c:65: char cfg_data_ok = (cfg_data[0]==0x12U || cfg_data[0]==0x21U);
	mov	dptr,#0x1003
	movx	a,@dptr
	mov	r2,a
	rlc	a
	subb	a,acc
	mov	r3,a
	clr	a
	cjne	r2,#0x12,00126$
	cjne	r3,#0x00,00126$
	inc	a
00126$:
	mov	r4,a
	jnz	00112$
	cjne	r2,#0x21,00129$
	cjne	r3,#0x00,00129$
	sjmp	00112$
00129$:
	mov	r5,#0x00
	sjmp	00113$
00112$:
	mov	r5,#0x01
00113$:
;	fx2pipe.c:67: SYNCDELAY;
	 nop 
	 nop 
	 nop 
	 nop 
	 nop 
	 nop 
	 nop 
	 nop 
	 nop 
	 nop 
	 nop 
	 nop 
	 nop 
	 nop 
	 nop 
	 nop 
	 nop 
;	fx2pipe.c:77: CPUCS = cfg_data_ok ? cfg_data[4] : 0x12;  // 0x12
	mov	a,r5
	jz	00114$
	mov	dptr,#0x1007
	movx	a,@dptr
	mov	r6,a
	sjmp	00115$
00114$:
	mov	r6,#0x12
00115$:
	mov	dptr,#_CPUCS
	mov	a,r6
	movx	@dptr,a
;	fx2pipe.c:78: SYNCDELAY;
	 nop 
	 nop 
	 nop 
	 nop 
	 nop 
	 nop 
	 nop 
	 nop 
	 nop 
	 nop 
	 nop 
	 nop 
	 nop 
	 nop 
	 nop 
	 nop 
	 nop 
;	fx2pipe.c:93: IFCONFIG = cfg_data_ok ? cfg_data[1] : 0xc3;
	mov	a,r5
	jz	00116$
	mov	dptr,#0x1004
	movx	a,@dptr
	mov	r5,a
	sjmp	00117$
00116$:
	mov	r5,#0xC3
00117$:
	mov	dptr,#_IFCONFIG
	mov	a,r5
	movx	@dptr,a
;	fx2pipe.c:94: SYNCDELAY;
	 nop 
	 nop 
	 nop 
	 nop 
	 nop 
	 nop 
	 nop 
	 nop 
	 nop 
	 nop 
	 nop 
	 nop 
	 nop 
	 nop 
	 nop 
	 nop 
	 nop 
;	fx2pipe.c:97: REVCTL = 0x03;  // See TRM...
	mov	dptr,#_REVCTL
	mov	a,#0x03
	movx	@dptr,a
;	fx2pipe.c:98: SYNCDELAY;
	 nop 
	 nop 
	 nop 
	 nop 
	 nop 
	 nop 
	 nop 
	 nop 
	 nop 
	 nop 
	 nop 
	 nop 
	 nop 
	 nop 
	 nop 
	 nop 
	 nop 
;	fx2pipe.c:101: PORTACFG = 0x00;
	mov	dptr,#_PORTACFG
	clr	a
	movx	@dptr,a
;	fx2pipe.c:102: SYNCDELAY; // maybe not needed
	 nop 
	 nop 
	 nop 
	 nop 
	 nop 
	 nop 
	 nop 
	 nop 
	 nop 
	 nop 
	 nop 
	 nop 
	 nop 
	 nop 
	 nop 
	 nop 
	 nop 
;	fx2pipe.c:105: FIFOPINPOLAR=0x00;
	mov	dptr,#_FIFOPINPOLAR
	clr	a
	movx	@dptr,a
;	fx2pipe.c:106: SYNCDELAY;
	 nop 
	 nop 
	 nop 
	 nop 
	 nop 
	 nop 
	 nop 
	 nop 
	 nop 
	 nop 
	 nop 
	 nop 
	 nop 
	 nop 
	 nop 
	 nop 
	 nop 
;	fx2pipe.c:109: EP6CFG=0x00U;  SYNCDELAY;
	mov	dptr,#_EP6CFG
	clr	a
	movx	@dptr,a
	 nop 
	 nop 
	 nop 
	 nop 
	 nop 
	 nop 
	 nop 
	 nop 
	 nop 
	 nop 
	 nop 
	 nop 
	 nop 
	 nop 
	 nop 
	 nop 
	 nop 
;	fx2pipe.c:110: EP2CFG=0x00U;  SYNCDELAY;
	mov	dptr,#_EP2CFG
	clr	a
	movx	@dptr,a
	 nop 
	 nop 
	 nop 
	 nop 
	 nop 
	 nop 
	 nop 
	 nop 
	 nop 
	 nop 
	 nop 
	 nop 
	 nop 
	 nop 
	 nop 
	 nop 
	 nop 
;	fx2pipe.c:111: EP6FIFOCFG=0x00U;  SYNCDELAY;
	mov	dptr,#_EP6FIFOCFG
	clr	a
	movx	@dptr,a
	 nop 
	 nop 
	 nop 
	 nop 
	 nop 
	 nop 
	 nop 
	 nop 
	 nop 
	 nop 
	 nop 
	 nop 
	 nop 
	 nop 
	 nop 
	 nop 
	 nop 
;	fx2pipe.c:112: EP2FIFOCFG=0x00U;  SYNCDELAY;
	mov	dptr,#_EP2FIFOCFG
	clr	a
	movx	@dptr,a
	 nop 
	 nop 
	 nop 
	 nop 
	 nop 
	 nop 
	 nop 
	 nop 
	 nop 
	 nop 
	 nop 
	 nop 
	 nop 
	 nop 
	 nop 
	 nop 
	 nop 
;	fx2pipe.c:113: OEA=0x00U;
	mov	_OEA,#0x00
;	fx2pipe.c:115: if(cfg_data[0]==0x12U) /* INPUT: USB->HOST */
	mov	a,r4
	jnz	00132$
	ljmp	00107$
00132$:
;	fx2pipe.c:126: EP6CFG = cfg_data[2];  // bulk: 0xe2 double-buffered; 0xe3 triple-; 0xe0 quad
	mov	dptr,#0x1005
	movx	a,@dptr
	mov	r4,a
	mov	dptr,#_EP6CFG
	movx	@dptr,a
;	fx2pipe.c:127: SYNCDELAY;
	 nop 
	 nop 
	 nop 
	 nop 
	 nop 
	 nop 
	 nop 
	 nop 
	 nop 
	 nop 
	 nop 
	 nop 
	 nop 
	 nop 
	 nop 
	 nop 
	 nop 
;	fx2pipe.c:131: FIFORESET = 0x80;  SYNCDELAY;  // NAK all requests from host. 
	mov	dptr,#_FIFORESET
	mov	a,#0x80
	movx	@dptr,a
	 nop 
	 nop 
	 nop 
	 nop 
	 nop 
	 nop 
	 nop 
	 nop 
	 nop 
	 nop 
	 nop 
	 nop 
	 nop 
	 nop 
	 nop 
	 nop 
	 nop 
;	fx2pipe.c:132: FIFORESET = 0x82;  SYNCDELAY;  // Reset individual EP (2,4,6,8)
	mov	dptr,#_FIFORESET
	mov	a,#0x82
	movx	@dptr,a
	 nop 
	 nop 
	 nop 
	 nop 
	 nop 
	 nop 
	 nop 
	 nop 
	 nop 
	 nop 
	 nop 
	 nop 
	 nop 
	 nop 
	 nop 
	 nop 
	 nop 
;	fx2pipe.c:133: FIFORESET = 0x84;  SYNCDELAY;
	mov	dptr,#_FIFORESET
	mov	a,#0x84
	movx	@dptr,a
	 nop 
	 nop 
	 nop 
	 nop 
	 nop 
	 nop 
	 nop 
	 nop 
	 nop 
	 nop 
	 nop 
	 nop 
	 nop 
	 nop 
	 nop 
	 nop 
	 nop 
;	fx2pipe.c:134: FIFORESET = 0x86;  SYNCDELAY;
	mov	dptr,#_FIFORESET
	mov	a,#0x86
	movx	@dptr,a
	 nop 
	 nop 
	 nop 
	 nop 
	 nop 
	 nop 
	 nop 
	 nop 
	 nop 
	 nop 
	 nop 
	 nop 
	 nop 
	 nop 
	 nop 
	 nop 
	 nop 
;	fx2pipe.c:135: FIFORESET = 0x88;  SYNCDELAY;
	mov	dptr,#_FIFORESET
	mov	a,#0x88
	movx	@dptr,a
	 nop 
	 nop 
	 nop 
	 nop 
	 nop 
	 nop 
	 nop 
	 nop 
	 nop 
	 nop 
	 nop 
	 nop 
	 nop 
	 nop 
	 nop 
	 nop 
	 nop 
;	fx2pipe.c:136: FIFORESET = 0x00;  SYNCDELAY;  // Resume normal operation. 
	mov	dptr,#_FIFORESET
	clr	a
	movx	@dptr,a
	 nop 
	 nop 
	 nop 
	 nop 
	 nop 
	 nop 
	 nop 
	 nop 
	 nop 
	 nop 
	 nop 
	 nop 
	 nop 
	 nop 
	 nop 
	 nop 
	 nop 
;	fx2pipe.c:148: EP6FIFOCFG = cfg_data[3]; /*0x0d //&0xfe*/;
	mov	dptr,#0x1006
	movx	a,@dptr
	mov	r4,a
	mov	dptr,#_EP6FIFOCFG
	movx	@dptr,a
;	fx2pipe.c:149: SYNCDELAY;
	 nop 
	 nop 
	 nop 
	 nop 
	 nop 
	 nop 
	 nop 
	 nop 
	 nop 
	 nop 
	 nop 
	 nop 
	 nop 
	 nop 
	 nop 
	 nop 
	 nop 
;	fx2pipe.c:154: EP6AUTOINLENH = 0x02; // MSB
	mov	dptr,#_EP6AUTOINLENH
	mov	a,#0x02
	movx	@dptr,a
;	fx2pipe.c:155: SYNCDELAY;
	 nop 
	 nop 
	 nop 
	 nop 
	 nop 
	 nop 
	 nop 
	 nop 
	 nop 
	 nop 
	 nop 
	 nop 
	 nop 
	 nop 
	 nop 
	 nop 
	 nop 
;	fx2pipe.c:156: EP6AUTOINLENL = 0x00; // LSB
	mov	dptr,#_EP6AUTOINLENL
	clr	a
	movx	@dptr,a
;	fx2pipe.c:157: SYNCDELAY;
	 nop 
	 nop 
	 nop 
	 nop 
	 nop 
	 nop 
	 nop 
	 nop 
	 nop 
	 nop 
	 nop 
	 nop 
	 nop 
	 nop 
	 nop 
	 nop 
	 nop 
	ret
00107$:
;	fx2pipe.c:165: else if(cfg_data[0]==0x21U) /* OUTPUT: HOST->USB */	
	cjne	r2,#0x21,00133$
	cjne	r3,#0x00,00133$
	sjmp	00134$
00133$:
	ret
00134$:
;	fx2pipe.c:176: EP2CFG = cfg_data[2];  // bulk: 0xa2 double-buffered; 0xa3 triple-; 0xa0 quad
	mov	dptr,#0x1005
	movx	a,@dptr
	mov	r2,a
	mov	dptr,#_EP2CFG
	movx	@dptr,a
;	fx2pipe.c:177: SYNCDELAY;
	 nop 
	 nop 
	 nop 
	 nop 
	 nop 
	 nop 
	 nop 
	 nop 
	 nop 
	 nop 
	 nop 
	 nop 
	 nop 
	 nop 
	 nop 
	 nop 
	 nop 
;	fx2pipe.c:181: FIFORESET = 0x80;  SYNCDELAY;  // NAK all requests from host. 
	mov	dptr,#_FIFORESET
	mov	a,#0x80
	movx	@dptr,a
	 nop 
	 nop 
	 nop 
	 nop 
	 nop 
	 nop 
	 nop 
	 nop 
	 nop 
	 nop 
	 nop 
	 nop 
	 nop 
	 nop 
	 nop 
	 nop 
	 nop 
;	fx2pipe.c:182: FIFORESET = 0x82;  SYNCDELAY;  // Reset individual EP (2,4,6,8)
	mov	dptr,#_FIFORESET
	mov	a,#0x82
	movx	@dptr,a
	 nop 
	 nop 
	 nop 
	 nop 
	 nop 
	 nop 
	 nop 
	 nop 
	 nop 
	 nop 
	 nop 
	 nop 
	 nop 
	 nop 
	 nop 
	 nop 
	 nop 
;	fx2pipe.c:183: FIFORESET = 0x84;  SYNCDELAY;
	mov	dptr,#_FIFORESET
	mov	a,#0x84
	movx	@dptr,a
	 nop 
	 nop 
	 nop 
	 nop 
	 nop 
	 nop 
	 nop 
	 nop 
	 nop 
	 nop 
	 nop 
	 nop 
	 nop 
	 nop 
	 nop 
	 nop 
	 nop 
;	fx2pipe.c:184: FIFORESET = 0x86;  SYNCDELAY;
	mov	dptr,#_FIFORESET
	mov	a,#0x86
	movx	@dptr,a
	 nop 
	 nop 
	 nop 
	 nop 
	 nop 
	 nop 
	 nop 
	 nop 
	 nop 
	 nop 
	 nop 
	 nop 
	 nop 
	 nop 
	 nop 
	 nop 
	 nop 
;	fx2pipe.c:185: FIFORESET = 0x88;  SYNCDELAY;
	mov	dptr,#_FIFORESET
	mov	a,#0x88
	movx	@dptr,a
	 nop 
	 nop 
	 nop 
	 nop 
	 nop 
	 nop 
	 nop 
	 nop 
	 nop 
	 nop 
	 nop 
	 nop 
	 nop 
	 nop 
	 nop 
	 nop 
	 nop 
;	fx2pipe.c:186: FIFORESET = 0x00;  SYNCDELAY;  // Resume normal operation. 
	mov	dptr,#_FIFORESET
	clr	a
	movx	@dptr,a
	 nop 
	 nop 
	 nop 
	 nop 
	 nop 
	 nop 
	 nop 
	 nop 
	 nop 
	 nop 
	 nop 
	 nop 
	 nop 
	 nop 
	 nop 
	 nop 
	 nop 
;	fx2pipe.c:189: OUTPKTEND = 0x82;  SYNCDELAY;
	mov	dptr,#_OUTPKTEND
	mov	a,#0x82
	movx	@dptr,a
	 nop 
	 nop 
	 nop 
	 nop 
	 nop 
	 nop 
	 nop 
	 nop 
	 nop 
	 nop 
	 nop 
	 nop 
	 nop 
	 nop 
	 nop 
	 nop 
	 nop 
;	fx2pipe.c:190: OUTPKTEND = 0x82;  SYNCDELAY;
	mov	dptr,#_OUTPKTEND
	mov	a,#0x82
	movx	@dptr,a
	 nop 
	 nop 
	 nop 
	 nop 
	 nop 
	 nop 
	 nop 
	 nop 
	 nop 
	 nop 
	 nop 
	 nop 
	 nop 
	 nop 
	 nop 
	 nop 
	 nop 
;	fx2pipe.c:191: switch(cfg_data[2]&0x03U)
	mov	a,r2
	rlc	a
	subb	a,acc
	anl	ar2,#0x03
	mov	r3,#0x00
	cjne	r2,#0x00,00135$
	cjne	r3,#0x00,00135$
	sjmp	00101$
00135$:
;	fx2pipe.c:193: case 0x00U:  OUTPKTEND = 0x82;  SYNCDELAY;  // Quad-buffered.
	cjne	r2,#0x03,00103$
	cjne	r3,#0x00,00103$
	sjmp	00102$
00101$:
	mov	dptr,#_OUTPKTEND
	mov	a,#0x82
	movx	@dptr,a
	 nop 
	 nop 
	 nop 
	 nop 
	 nop 
	 nop 
	 nop 
	 nop 
	 nop 
	 nop 
	 nop 
	 nop 
	 nop 
	 nop 
	 nop 
	 nop 
	 nop 
;	fx2pipe.c:194: case 0x03U:  OUTPKTEND = 0x82;  SYNCDELAY;  // Triple-buffered.
00102$:
	mov	dptr,#_OUTPKTEND
	mov	a,#0x82
	movx	@dptr,a
	 nop 
	 nop 
	 nop 
	 nop 
	 nop 
	 nop 
	 nop 
	 nop 
	 nop 
	 nop 
	 nop 
	 nop
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
;	fx2pipe.c:219: void main()
;	-----------------------------------------
;	 function main
;	-----------------------------------------
_main:
;	fx2pipe.c:221: Initialize();
	lcall	_Initialize
00102$:
	sjmp	00102$
	.area CSEG    (CODE)
	.area CONST   (CODE)
	.area XINIT   (CODE)
	.area CABS    (ABS,CODE)

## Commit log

2019-10-25 Add DIR solder jumper comment in the schematic.
    [ensaimedia.sch]
2019-10-25 Adición de índice al readme
2019-11-04 Cambiado pinout del core a la última versión de la PCB.
2019-11-04 Añadido comentario sobre el modo fundamental del cristal usado
